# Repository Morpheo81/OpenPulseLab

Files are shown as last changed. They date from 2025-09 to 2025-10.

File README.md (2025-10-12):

# OpenPulseLab
A Low-Cost, Open-Source ECG Monitor for educational and research uses

> [!NOTE]
> This project is currently under active development and is a work in progress (WIP).

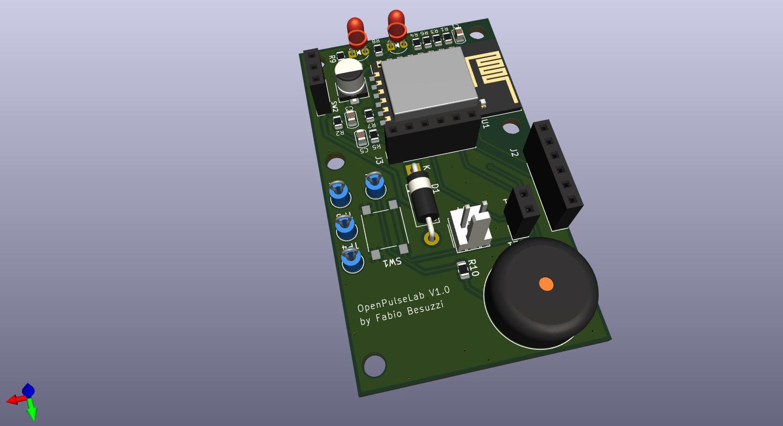
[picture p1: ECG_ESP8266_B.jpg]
ECG ESP8266

---

### A Note on Project Purpose and Responsibility

**This device is an educational and research prototype. It is NOT a certified medical device and should NEVER be used for diagnostic purposes.**

The primary goal of this project is to create an accessible, affordable, and open-source platform for learning about biometrics, signal processing, and IoT. Its simplicity is a feature, designed to lower the barrier to entry for students, hobbyists, and developers in emerging economies. The data quality is intentionally limited in this version, but can be improved with advanced software. By using this project, you acknowledge and agree to the full disclaimer below.

---

## ⚠️ Legal Disclaimer ⚠️

This project is provided "as is," without any warranty of any kind, either express or implied, including, but not limited to, the implied warranties of merchantability, fitness for a particular purpose, or non-infringement. In no event shall the authors or copyright holders be liable for any claim, damages, or other liability, whether in an action of contract, tort, or otherwise, arising from, out of, or in connection with the software, hardware, or the use or other dealings in the project.

**Do not use this device for medical diagnosis, treatment, or any clinical application. Consult a certified medical professional for any health-related concerns.**

---

### About the Project

This project leverages an **ESP8266 microcontroller** to create a simple, Wi-Fi enabled ECG monitor. It processes the analog signals from an **AD8232 ECG sensor module** and serves a web page via an on-board web server. Users can access this page from any web browser to view real-time heart data and save it. The device also includes hardware for **lead-off detection** and a **buzzer/LED** for error signaling.

* **Open and Accessible:** All hardware schematics, firmware, and documentation are provided.
* **Low-Cost:** Built with readily available and inexpensive components.
* **Self-Contained:** Designed to run on a battery, ensuring full electrical isolation and safety from the mains power supply.

### How It Works

1.  **Signal Acquisition:** The AD8232 sensor module captures the electrical signals of the heart.
2.  **Signal Conversion:** The ESP8266's analog-to-digital converter (ADC) reads the output from the AD8232.
3.  **Data Transmission:** The ESP8266 acts as a web server, broadcasting the raw data via Wi-Fi and using **WebSockets** for real-time streaming.
4.  **Data Visualization:** A simple HTML/JavaScript front-end displays the data on a graph in a web browser. A software filter (median on X, moving average on Y) is applied to smooth the raw data.

**Here an example of the Web Server running on ESP8266**
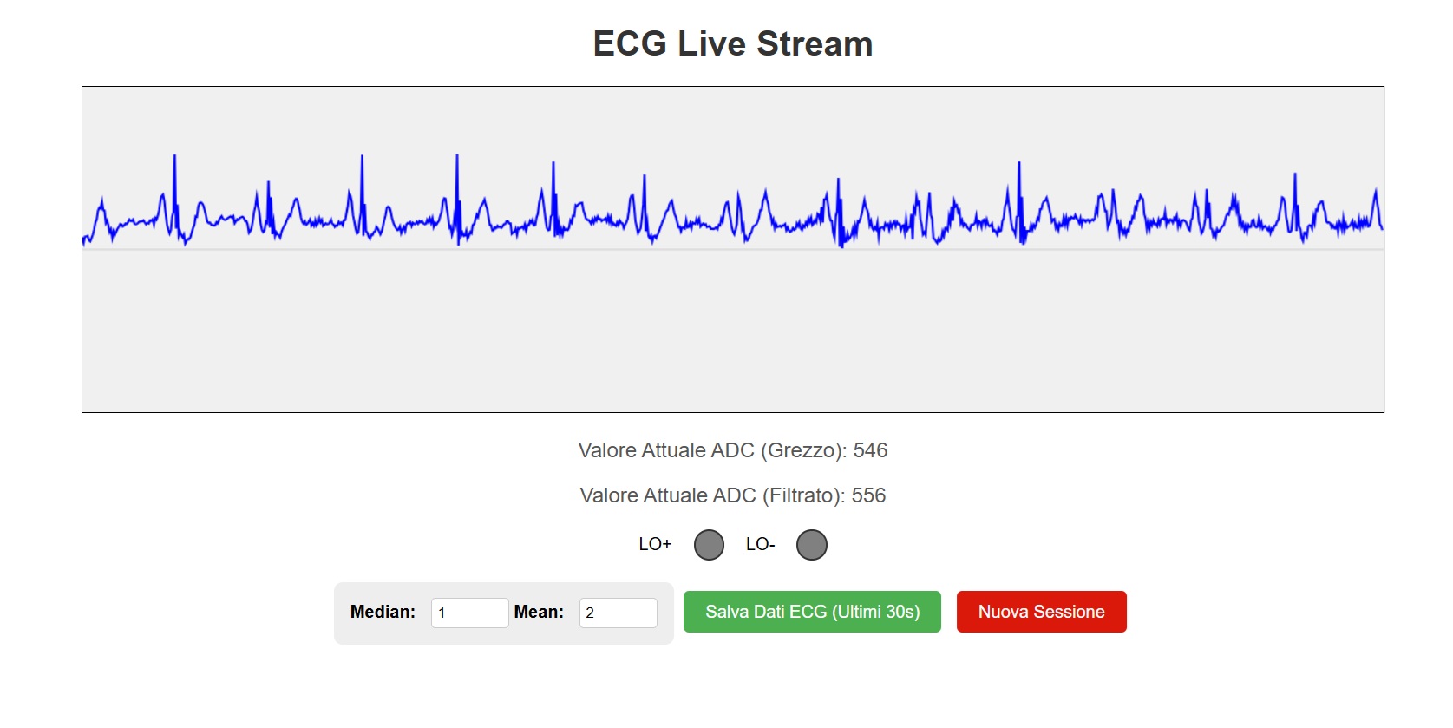
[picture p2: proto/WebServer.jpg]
WebServer


### Potential Applications

While not a medical tool, this project has several fascinating applications:

* **Educational:** A practical, hands-on tool for teaching electronics, programming, and biometrics.
* **Research:** A base platform for research into advanced signal processing algorithms (e.g., using AI to identify patterns in nerve impulses).
* **Human-Computer Interface (HCI):** The same principles can be used to detect neuromuscular signals, allowing the device to act as a controller for a PC or other machines.

### Getting Started

To build your prototipe device, you will need:

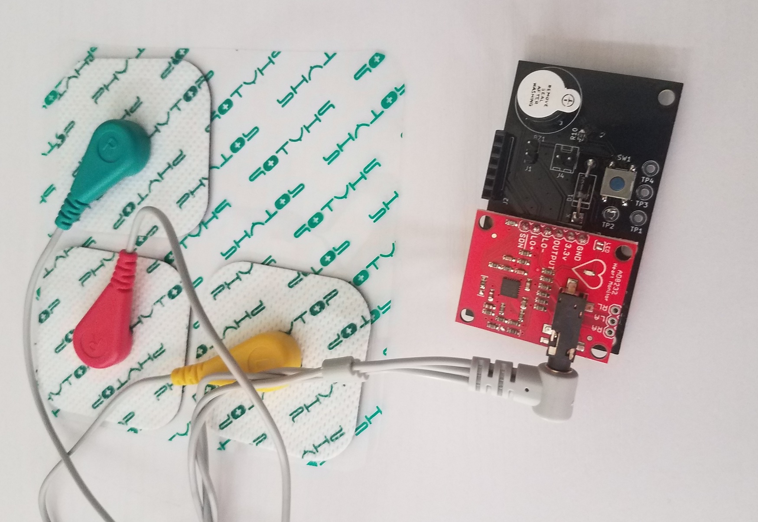
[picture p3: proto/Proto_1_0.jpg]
Board


* **Components: for Rev 1.0**
    * Buzzer (BZ1) - not mandatory
    * 0.1uF capacitors (C1, C3)
    * 100uF capacitor (C2)
    * capacitor (C5)
    * diodes (D1, D2)
    * PinSocket 1x06 (J2, J3) and 1x02 (J1) connectors
    * Molex 1x02 connector (J4)
    * LED for error (LED1)
    * LED for power (LED2)
    * 10K resistors (R1, R6)
    * 1K resistor (R2)
    * 22K resistors (R3, R4, R5)
    * 100 resistors (R8, R9, R10)
    * SW_Push button (SW1)
    * SW_DIP_x01 switch (SW2)
    * test points (TP1, TP2, TP3, TP4)
    * ESP-12F WiFi module (U1)
 NOTE: SMD resistor and ceramic capacitor are 0805
* **Tools:**
    * Soldering iron and soldering materials.
    * **AD8232 module with electrode.**
    * Serial programmer.
 
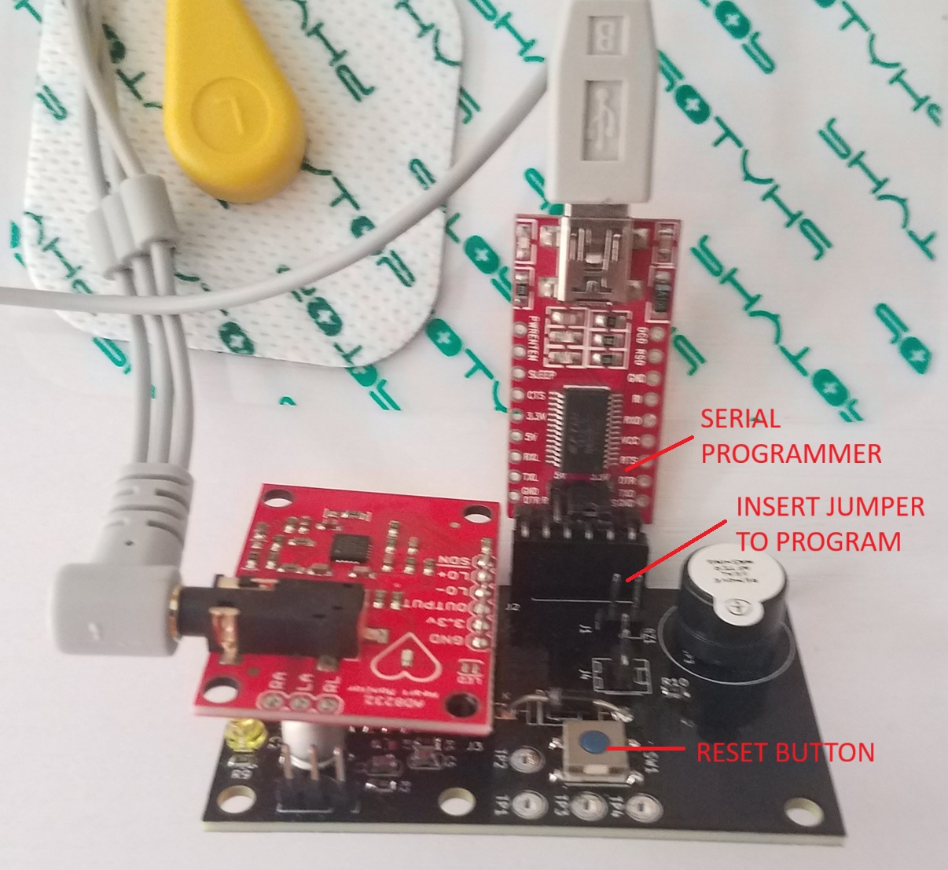
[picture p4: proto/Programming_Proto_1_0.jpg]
Programming


* **Firmware & Libraries:**
    * `ECG_ESP8266.ino` firmware file example for the ECG - main topic
    * `ECG_muscle_ESP8266.ino` firmware file example for use this platform to detect the activation of muscles
    * Arduino Libraries: `ESP8266WiFi`, `ESP8266WebServer`, `WebSocketsServer` by Markus Sattler, `ArduinoJson`
* **Files:**
    * The hardware files are in the `KiCad` folder.
    * The firmware files are in the `ArduinoIDE` folder.
    * The proto of the box is in the `FreeCAD` folder.

### Example of Electrode Placement and Important Notes

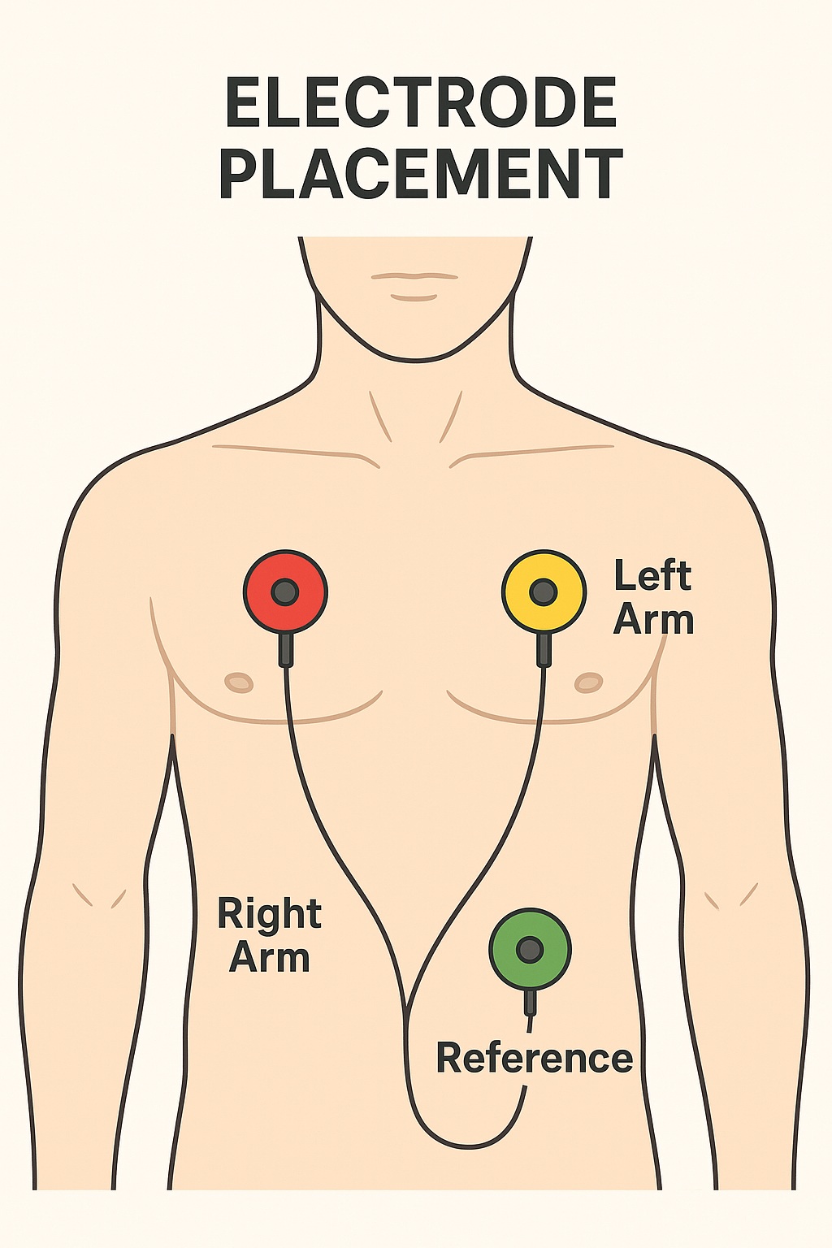
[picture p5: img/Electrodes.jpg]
descrizione


This device uses TENS/EMS (Transcutaneous Electrical Nerve Stimulation / Electrical Muscle Stimulation) electrodes instead of traditional, single-use ECG electrodes. While standard ECG electrodes are specifically designed for low impedance and optimal signal fidelity, they are often expensive and intended for single use due to their hydrogel-based adhesive.

Our choice to use TENS/EMS pads is a deliberate design decision to prioritize reusability and user convenience. These pads, commonly used for muscle stimulation, have a more durable adhesive, allowing for multiple uses before replacement. This makes the OpenPulseLab device more cost-effective and accessible, particularly for educational and hobbyist purposes.

It's important to note the technical trade-off involved. The impedance of TENS/EMS pads is typically higher than that of medical-grade ECG electrodes. This can result in a weaker signal from the AD8232 sensor. If you choose to use different types of electrodes, such as standard ECG electrodes, you may need to re-evaluate and adjust the amplification factors and any filtering thresholds within the firmware to achieve the best possible signal quality.

### Licensing

This project is released under the **Creative Commons Attribution-ShareAlike 4.0 International (CC BY-SA 4.0)** license. This means you are free to share and adapt the material for any purpose, even commercially, as long as you provide appropriate attribution and distribute your contributions under the same license.

**Copyright (c) 2025 Fabio Besuzzi**

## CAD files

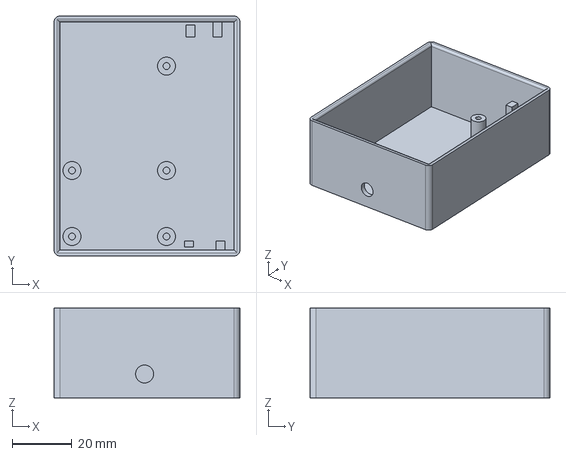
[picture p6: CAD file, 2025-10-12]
FreeCAD/Scatola_ECG.FCStd
62.0 x 80.0 x 30.0 mm

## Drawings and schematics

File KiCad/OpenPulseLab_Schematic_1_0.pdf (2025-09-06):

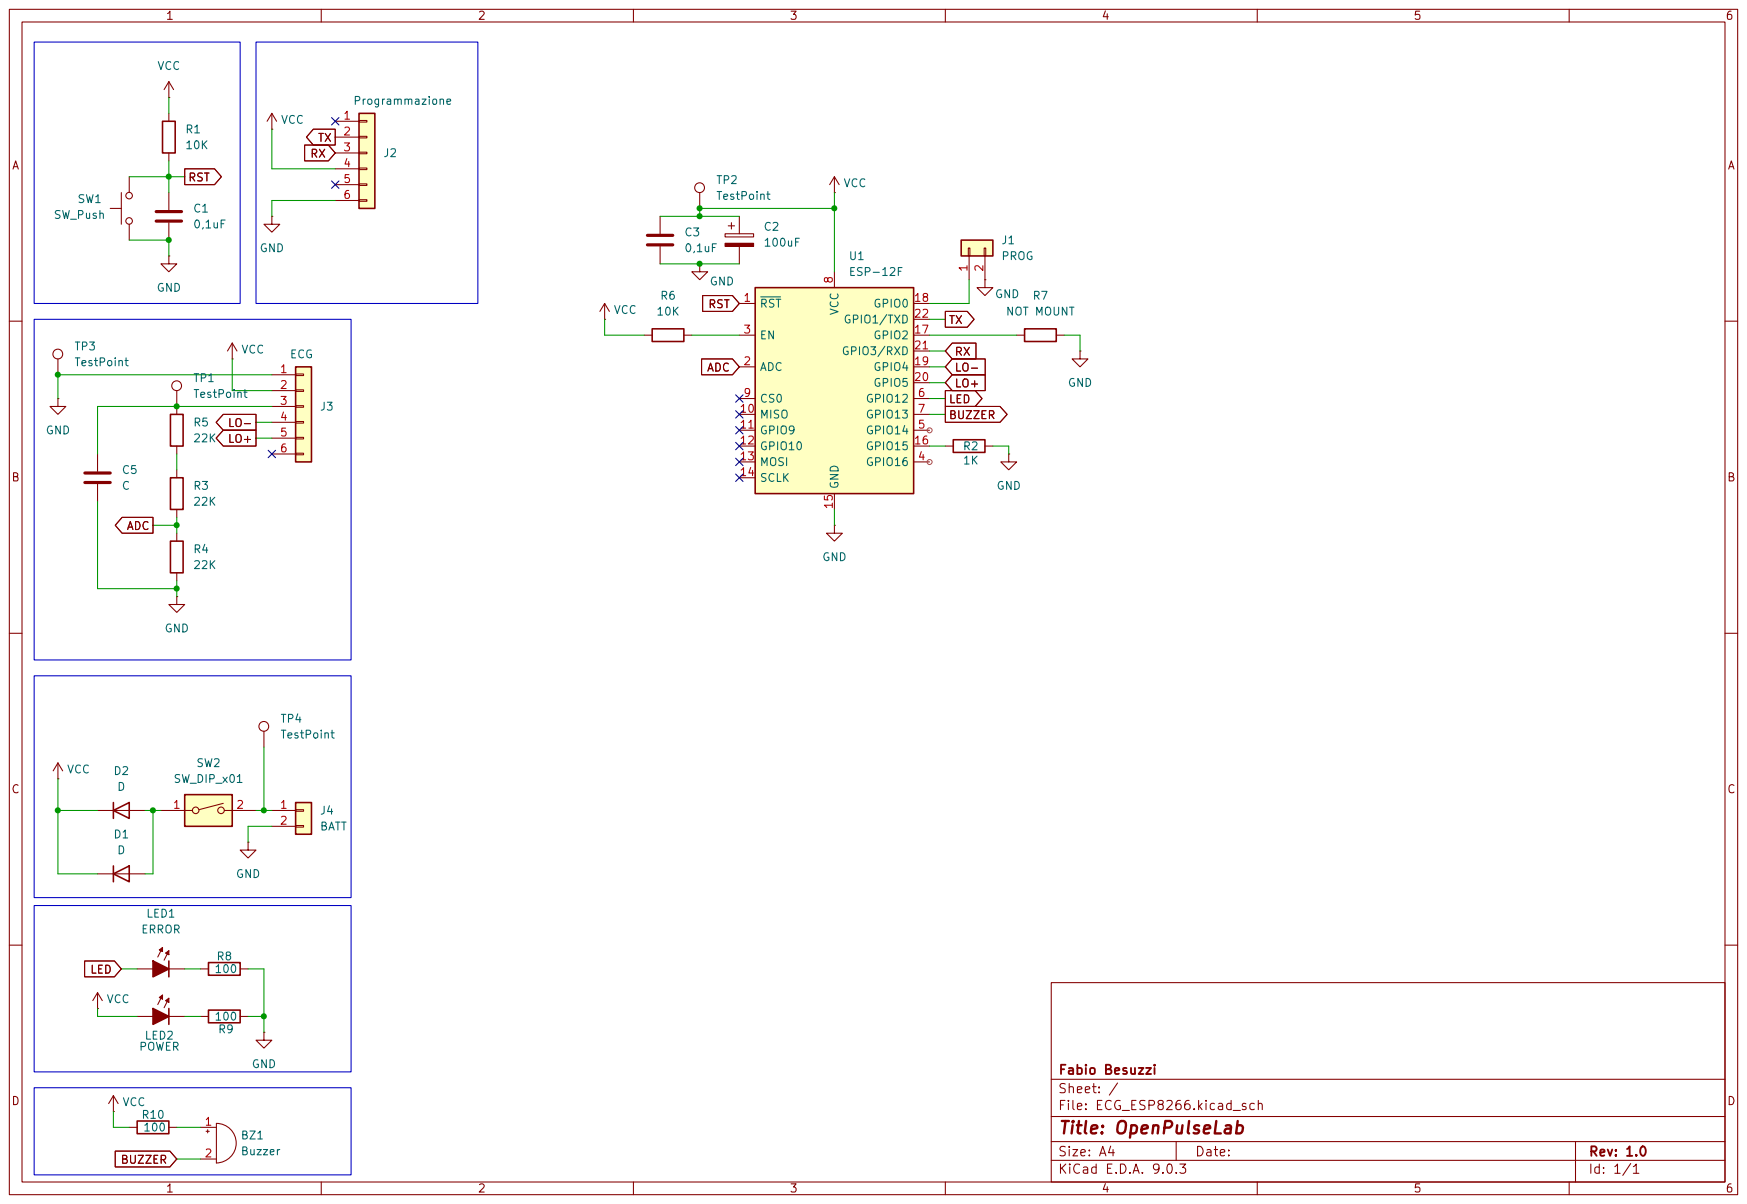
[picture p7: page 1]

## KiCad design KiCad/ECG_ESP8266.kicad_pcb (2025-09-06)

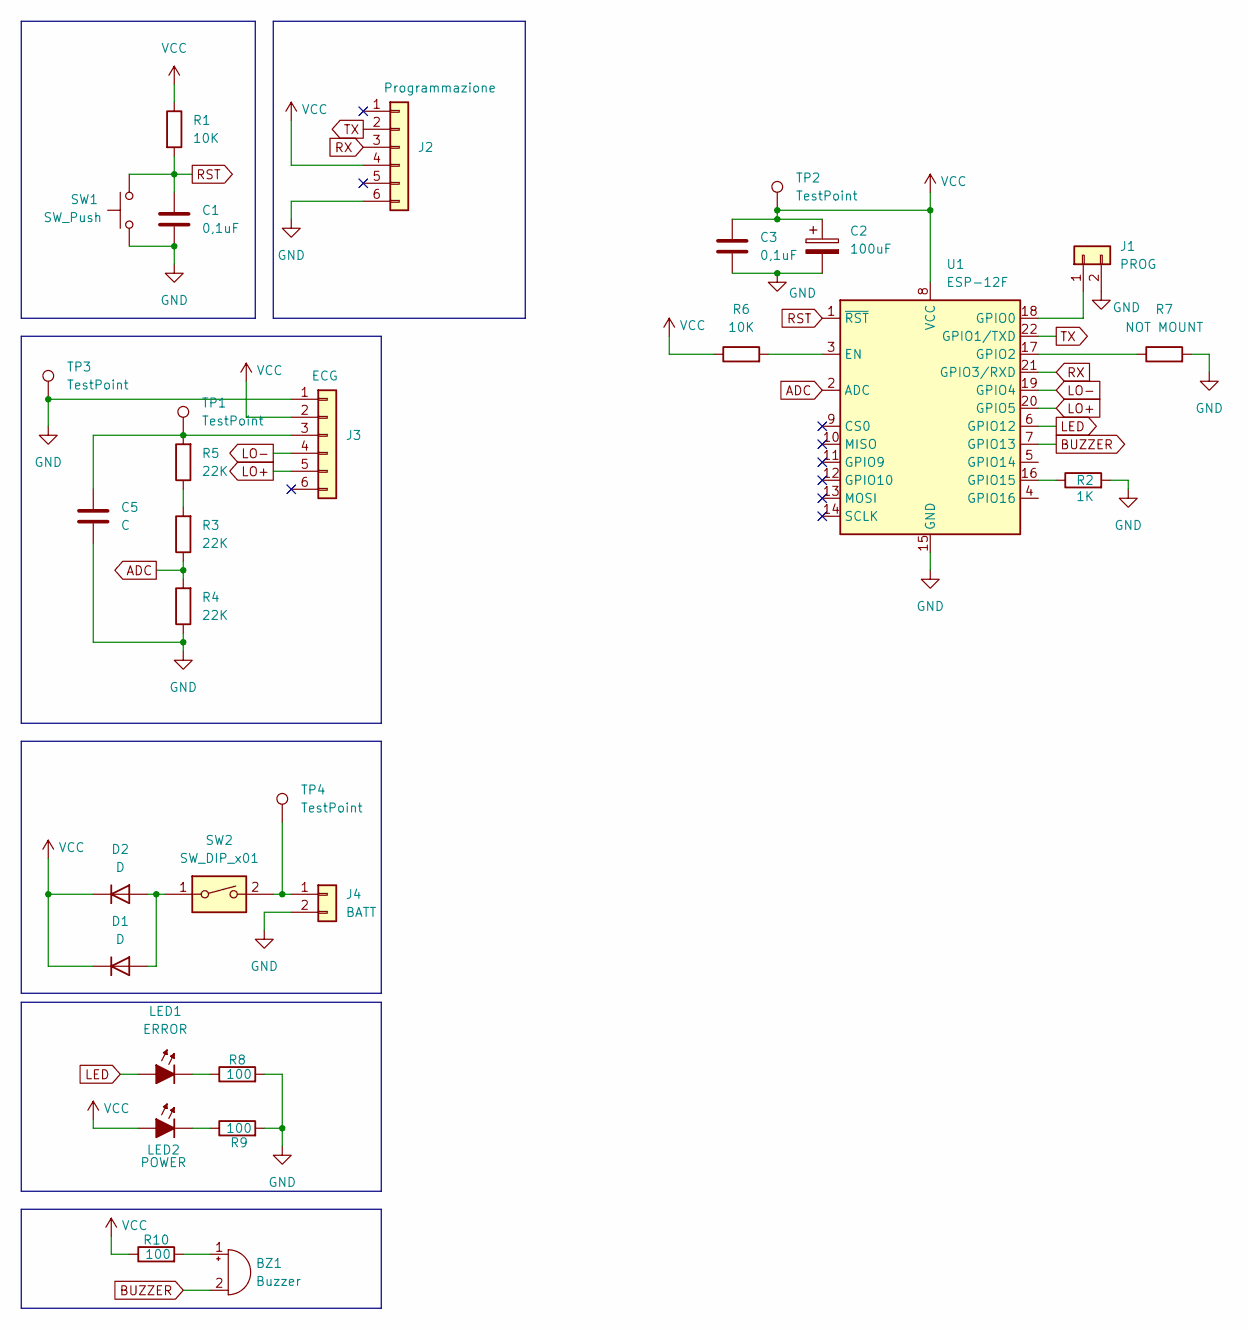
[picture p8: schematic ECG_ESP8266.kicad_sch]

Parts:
BZ1: Buzzer; Buzzer_15x7.5RM7.6
C1, C3: 0,1uF; C_0805_2012Metric
C2: 100uF; CP_Elec_5x5.3
C5: C; C_0805_2012Metric
D1: D; D_DO-15_P12.70mm_Horizontal
D2: D; D_0805_2012Metric
J1: PROG; PinSocket_1x02_P2.54mm_Vertical
J2: Programmazione; PinSocket_1x06_P2.54mm_Vertical
J3: ECG; PinSocket_1x06_P2.54mm_Vertical
J4: BATT; Molex_KK-254_AE-6410-02A_1x02_P2.54mm_Vertical
LED1: ERROR; LED_D3.0mm
LED2: POWER; LED_D3.0mm
R1, R6: 10K; R_0805_2012Metric
R2: 1K; R_0805_2012Metric
R3, R4, R5: 22K; R_0805_2012Metric
R7: NOT MOUNT; R_0805_2012Metric
R8, R9, R10: 100; R_0805_2012Metric
SW1: SW_Push; SW_Push_1P1T_NO_6x6mm_H9.5mm
SW2: SW_DIP_x01; PinSocket_1x03_P2.54mm_Vertical
TP1, TP2, TP3, TP4: TestPoint; TestPoint_Loop_D2.54mm_Drill1.5mm_Beaded
U1: ESP-12F; ESP-12E

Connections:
ADC: R3.1, R4.2, U1.2 (ADC)
BUZZER: BZ1.2 (-), U1.7 (GPIO13)
GND: C1.2, C2.2, C3.2, C5.2, J1.2, J2.6, J3.1, J4.2, R2.2, R4.1, R7.2, R8.2, R9.2, SW1.1, TP3.1, U1.15 (GND)
LED: LED1.2 (A), U1.6 (GPIO12)
LO+: J3.5, U1.20 (GPIO5)
LO-: J3.4, U1.19 (GPIO4)
unnamed: BZ1.1 (+), R10.2
unnamed: D1.2 (A), D2.2 (A), SW2.1
unnamed: J1.1, U1.18 (GPIO0)
unnamed: C5.1, J3.3, R5.2, TP1.1
unnamed: J4.1, SW2.2, TP4.1
unnamed: LED1.1 (K), R8.1
unnamed: LED2.1 (K), R9.1
unnamed: R3.2, R5.1
unnamed: R6.2, U1.3 (EN)
unnamed: R7.1, U1.17 (GPIO2)
unnamed: R2.1, U1.16 (GPIO15)
RST: C1.1, R1.2, SW1.2, U1.1 (~RST)
RX: J2.3, U1.21 (GPIO3/RXD)
TX: J2.2, U1.22 (GPIO1/TXD)
VCC: C2.1, C3.1, D1.1 (K), D2.1 (K), J2.4, J3.2, LED2.2 (A), R1.1, R6.1, R10.1, TP2.1, U1.8 (VCC)

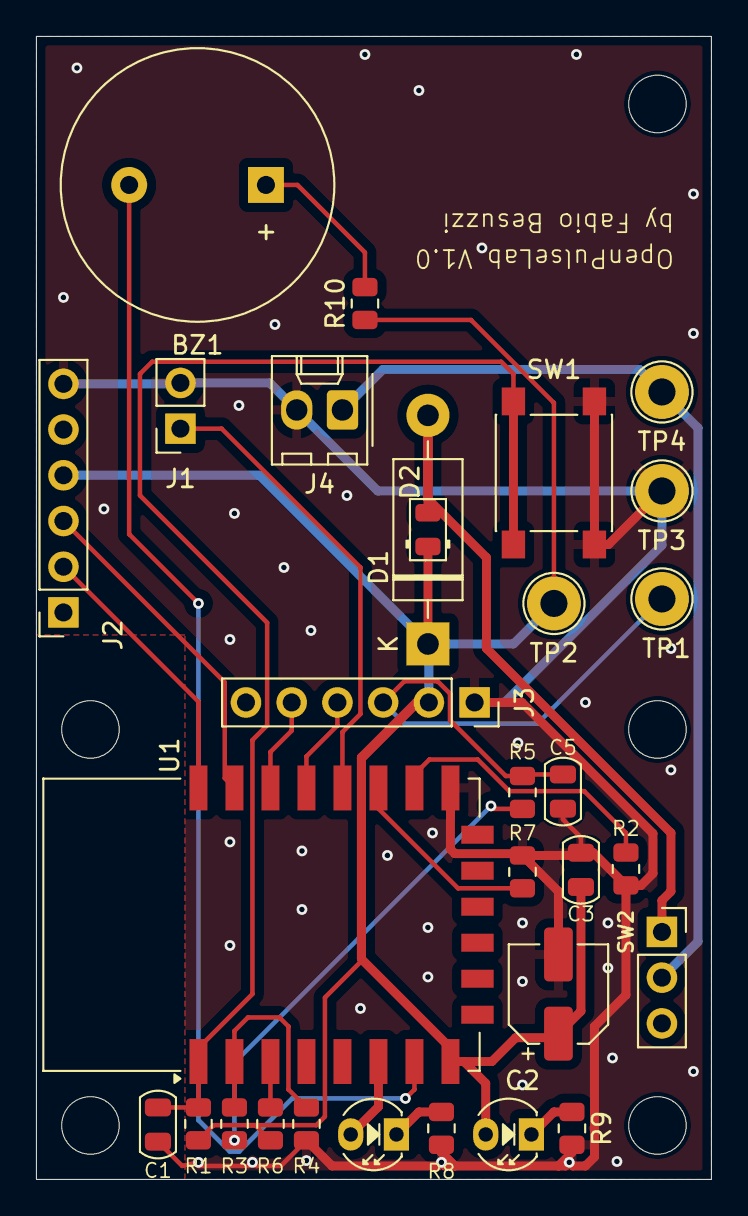
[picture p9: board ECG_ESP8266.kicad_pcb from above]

Board: 2 copper layers, 37.5 x 63.5 mm, 30 parts (0 on the bottom side), 21 nets.

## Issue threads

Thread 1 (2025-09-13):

Box for the device

Morpheo81, 2025-09-13:
Design of a case for the device with STL files printable via 3D printing. The case should be reasonably ergonomic and compact, and it must contain an 18650 battery to power the device.

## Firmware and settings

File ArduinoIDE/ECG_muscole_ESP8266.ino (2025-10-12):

#include <ESP8266WiFi.h>
#include <ESP8266WebServer.h>
#include <WebSocketsServer.h> // Libreria WebSockets di Markus Sattler
#include <ArduinoJson.h>      // Libreria per la gestione di JSON (installala!)

// --- Configurazione Wi-Fi Access Point ---
const char *ssid = "ECG_Monitor";     // Nome della rete Wi-Fi che l'ESP creerà
const char *password = "password123"; // Password della rete (puoi lasciarla vuota: const char *password = ""; per nessuna password)

// --- Inizializzazione dei Server ---
ESP8266WebServer server(80);         // Server HTTP sulla porta 80
WebSocketsServer webSocket = WebSocketsServer(81); // Server WebSockets sulla porta 81

// --- Configurazione Pin Lead-Off Detection (AD8232) ---
// Collega LO+ del AD8232 a D2 (GPIO4) e LO- a D1 (GPIO5) sul tuo NodeMCU/Wemos.
// Verifica la tua board per i pin GPIO effettivi associati a D1, D2, ecc.
// L'AD8232 invia HIGH quando il lead è scollegato, LOW quando è connesso.
// Se il tuo modulo ha logica invertita, potresti dover invertire i 0/1 nel JS.
const int LO_PLUS_PIN = 4;  // Esempio: pin D2 (GPIO4) collegato a LO+ del AD8232
const int LO_MINUS_PIN = 5; // Esempio: pin D1 (GPIO5) collegato a LO- del AD8232

// Pin del LED aggiuntivo da utilizzare per segnalazioni di errori o stato di funzionamento (GPIO12)
const int LED_PIN = 12;

// Pin del BUZZER da utilizzare per allarmi (GPIO13)
const int BUZZER_PIN = 13;


// --- Pagina HTML da servire al Browser ---
// Contiene HTML, CSS e JavaScript per la visualizzazione e le funzionalità
const char* htmlPage = R"rawliteral(

<!DOCTYPE html>
<html>
<head>
    <title>EMG Muscolare Differenziale</title>
    <meta name="viewport" content="width=device-width, initial-scale=1">
    <style>
        body { font-family: Arial, sans-serif; text-align: center; margin-top: 50px; }
        /* Il canvas non è più necessario ma manteniamo lo stile per consistenza, nascondendolo o rimuovendolo */
        canvas { display: none; } 
        h1 { color: #333; }
        p { font-size: 1.2em; color: #555; }
        /* Stile per i parametri di controllo */
        .control-params {
            margin-top: 20px;
            background-color: #eee;
            padding: 15px;
            border-radius: 8px;
            display: inline-block;
            text-align: left;
        }
        .control-params label {
            display: block;
            margin-top: 10px;
            font-weight: bold;
        }
        .control-params input[type="number"] {
            width: 80px;
            padding: 5px;
            border-radius: 4px;
            border: 1px solid #ccc;
        }
        /* Stile per gli indicatori */
        .indicator-container {
            margin-top: 30px;
            margin-bottom: 30px;
            display: flex;
            justify-content: center;
            gap: 40px;
            align-items: center;
        }
        .indicator-group {
            text-align: center;
        }
        .indicator-label {
            font-size: 1.5em;
            font-weight: bold;
            color: #333;
            margin-bottom: 10px;
        }
        .indicator {
            width: 40px;
            height: 40px;
            border-radius: 50%;
            background-color: gray; /* Spento */
            border: 3px solid #333;
            box-shadow: 0 0 10px rgba(0, 0, 0, 0.2);
            transition: background-color 0.1s;
        }
        .indicator.active-muscle-1 {
            background-color: #2196F3; /* Blu per Muscolo 1 */
            box-shadow: 0 0 20px #2196F3, 0 0 30px #2196F3;
        }
        .indicator.active-muscle-2 {
            background-color: #FFC107; /* Giallo/Arancio per Muscolo 2 */
            box-shadow: 0 0 20px #FFC107, 0 0 30px #FFC107;
        }
    </style>
</head>
<body>
    <h1>Muscle Activations</h1>

    <div class="indicator-container">
        <div class="indicator-group">
            <div class="indicator-label">MUSCLE 1</div>
            <div id="muscle1Indicator" class="indicator"></div>
        </div>
        <div class="indicator-group">
            <div class="indicator-label">MUSCLE 2</div>
            <div id="muscle2Indicator" class="indicator"></div>
        </div>
    </div>
    
    <p>DATA: ROW: <span id="currentActivityValue">--</span></p>
    <p>DATA: Filtered: <span id="currentNormalizedValue">--</span></p>

    <div class="control-params">
        <h3>Sensibility</h3>
        
        <label for="activationThreshold">Treshold (0-512):</label>
        <input type="number" id="activationThreshold" value="50" min="1" max="512">
        
        <label for="sensitivityFactor">Amplification:</label>
        <input type="number" id="sensitivityFactor" value="1.0" min="0.1" step="0.1">
    </div>

    <canvas id="ecgCanvas" width="1" height="1"></canvas> 
    
    <script>
        var ws;
        var adcMidPoint = 512; // Punto medio per un ADC a 10 bit (0-1023)
        
        // --- Elementi UI ---
        var muscle1Indicator = document.getElementById('muscle1Indicator');
        var muscle2Indicator = document.getElementById('muscle2Indicator');
        var thresholdInput = document.getElementById('activationThreshold');
        var sensitivityInput = document.getElementById('sensitivityFactor');
        
        // --- Parametri di Controllo ---
        var threshold = parseFloat(thresholdInput.value);
        var sensitivity = parseFloat(sensitivityInput.value);

        // Event Listeners per i cambiamenti dei valori
        thresholdInput.addEventListener('change', function() {
            threshold = parseFloat(this.value);
            console.log('Soglia aggiornata:', threshold);
        });
        sensitivityInput.addEventListener('change', function() {
            sensitivity = parseFloat(this.value);
            console.log('Sensibilità aggiornata:', sensitivity);
        });

        // --- Funzione Principale di Attivazione Muscolare ---
        function checkMuscleActivation(rawValue) {
            // 1. Calcola lo scostamento dal punto medio (segnala quale muscolo è attivo)
            // Se rawValue > 512, lo scostamento è positivo (Muscolo 1, es. Flessore)
            // Se rawValue < 512, lo scostamento è negativo (Muscolo 2, es. Estensore)
            var deviation = rawValue - adcMidPoint;

            // 2. Calcola l'intensità (attività) in valore assoluto
            var absoluteActivity = Math.abs(deviation);
            
            // 3. Applica il fattore di sensibilità (amplificazione)
            var normalizedActivity = absoluteActivity * sensitivity;

            // 4. Aggiorna i valori visualizzati
            document.getElementById('currentActivityValue').innerText = deviation.toFixed(0);
            document.getElementById('currentNormalizedValue').innerText = normalizedActivity.toFixed(0);

            // 5. Logica di Attivazione
            if (normalizedActivity > threshold) {
                // L'attività è abbastanza forte
                if (deviation > 0) {
                    // Muscolo 1 è dominante (scostamento positivo)
                    muscle1Indicator.classList.add('active-muscle-1');
                    muscle2Indicator.classList.remove('active-muscle-2');
                    console.log("Muscolo 1 ATTIVO (Flessione)");
                } else {
                    // Muscolo 2 è dominante (scostamento negativo)
                    muscle2Indicator.classList.add('active-muscle-2');
                    muscle1Indicator.classList.remove('active-muscle-1');
                    console.log("Muscolo 2 ATTIVO (Estensione)");
                }
            } else {
                // Nessuna attività sufficiente
                muscle1Indicator.classList.remove('active-muscle-1');
                muscle2Indicator.classList.remove('active-muscle-2');
            }
        }

        // --- Funzione per Connettersi al WebSocket ---
        function connectWebSocket() {
            ws = new WebSocket('ws://' + location.hostname + ':81/');

            ws.onopen = function() {
                console.log('WebSocket Connesso!');
            };

            ws.onmessage = function(event) {
                // Assumiamo che l'ESP8266 invii ancora un JSON con il valore ADC
                try {
                    var dataPacket = JSON.parse(event.data);
                    var rawValue = dataPacket.ecg; // Riusiamo la chiave 'ecg' ma ora rappresenta l'EMG
                    
                    if (!isNaN(rawValue)) {
                        checkMuscleActivation(rawValue);
                    }
                } catch (e) {
                    console.error("Errore nel parsing JSON o dati non validi:", e, event.data);
                }
            };

            ws.onclose = function() {
                console.log('WebSocket Disconnesso, tento di riconnettermi...');
                // Spegne le spie in caso di disconnessione
                muscle1Indicator.classList.remove('active-muscle-1');
                muscle2Indicator.classList.remove('active-muscle-2');
                setTimeout(connectWebSocket, 3000); // Tenta di riconnettersi dopo 3 secondi
            };

            ws.onerror = function(error) {
                console.error('Errore WebSocket:', error);
            };
        }

        // --- Inizializzazione all'apertura della Pagina ---
        window.onload = function() {
            connectWebSocket(); // Avvia la connessione WebSocket
        };
    </script>
</body>
</html>

)rawliteral";

// --- Gestore Eventi WebSockets ---
void webSocketEvent(uint8_t num, WStype_t type, uint8_t * payload, size_t length) {
  switch(type) {
    case WStype_DISCONNECTED:
      Serial.printf("[%u] Client Disconnesso!\n", num);
      break;
    case WStype_CONNECTED: {
      IPAddress ip = webSocket.remoteIP(num);
      Serial.printf("[%u] Client Connesso da %d.%d.%d.%d URL: %s\n", num, ip[0], ip[1], ip[2], ip[3], payload);
      webSocket.sendTXT(num, "Benvenuto al monitor ECG!"); // Invia un messaggio di benvenuto al nuovo client
    }
    break;
    case WStype_TEXT:
      Serial.printf("[%u] Ricevuto testo: %s\n", num, payload);
      // Puoi aggiungere logica qui se il browser invia comandi all'ESP
      break;
    case WStype_BIN:
    case WStype_PING:
    case WStype_PONG:
    case WStype_ERROR:
      // Ignora questi tipi di messaggi per questo progetto
      break;
  }
}

// --- Funzione di Setup (Eseguita una sola volta all'avvio dell'ESP) ---
void setup() {
  Serial.begin(115200); // Inizializza la comunicazione seriale per il debug
  Serial.println("\n");
  Serial.println("Avvio ECG Monitor...");

  // Configura i pin per la Lead-Off Detection come input
  // L'AD8232 tipicamente ha uscite Lead-Off che sono HIGH (pull-up interno)
  // quando l'elettrodo è scollegato, e LOW quando è collegato.
  // Quindi, INPUT sarà sufficiente. Se hai problemi, prova INPUT_PULLUP.
  pinMode(LO_PLUS_PIN, INPUT);
  pinMode(LO_MINUS_PIN, INPUT);

  //Configurazione dei pin del LED e del BUZZER 
  pinMode(LED_PIN, OUTPUT);
  pinMode(BUZZER_PIN, OUTPUT);
  //Impostazione del valore di default: il LED è attivo alto mentre il BUZZER è attivo basso
  digitalWrite(LED_PIN, LOW);
  digitalWrite(BUZZER_PIN, HIGH);


  // Configura l'ESP come Access Point Wi-Fi
  WiFi.softAP(ssid, password);
  Serial.print("Access Point \"");
  Serial.print(ssid);
  Serial.println("\" creato.");
  Serial.print("Indirizzo IP per la connessione: ");
  Serial.println(WiFi.softAPIP()); // Stampa l'IP dell'ESP (solitamente 192.168.4.1)

  // Configura il server HTTP per servire la pagina web
  server.on("/", HTTP_GET, []() {
    server.send(200, "text/html", htmlPage); // Invia la pagina HTML al browser
  });
  server.begin();
  Serial.println("Server HTTP avviato sulla porta 80.");

  // Avvia il server WebSockets e registra la funzione di callback per gli eventi
  webSocket.begin();
  webSocket.onEvent(webSocketEvent);
  Serial.println("Server WebSockets avviato sulla porta 81.");

  // Inizializza il pin analogico A0
  // La risoluzione ADC è nativamente a 10 bit sull'ESP8266, quindi analogRead() fornirà valori 0-1023.
  Serial.println("ADC configurato nativamente a 10 bit.");
  Serial.println("Pronto per lo streaming ECG.");
}

int ecgValue;

// --- Funzione Loop (Eseguita continuamente dopo il setup) ---
void loop() {
  // Gestisce le richieste del server HTTP (per servire la pagina web)
  server.handleClient();
  // Gestisce gli eventi del server WebSockets (nuove connessioni, messaggi, ecc.)
  webSocket.loop();


  // Legge lo stato dei pin di Lead-Off Detection
  // L'AD8232 tipicamente invia HIGH (1) quando il lead è scollegato (problema),
  // e LOW (0) quando è collegato (OK).
  int loPlusStatus = digitalRead(LO_PLUS_PIN);
  int loMinusStatus = digitalRead(LO_MINUS_PIN);
int temp_ECG[9];
digitalWrite(LED_PIN, LOW);
  int c1;
  int c2;
  int c3;
  for(c1=0;c1<5;c1++) temp_ECG[c1] = 0;
  for(c1=0;c1<5;c1++)
  {
    ecgValue = analogRead(A0);
    digitalWrite(BUZZER_PIN, HIGH);
    if(ecgValue>760){
      digitalWrite(BUZZER_PIN, LOW);
      digitalWrite(LED_PIN, HIGH);
    }
    for(c2=0;c2<5-1;c2++)
    {    
      if(ecgValue>temp_ECG[c2])
      {
        for(c3=c2;c3<5-1;c3++)
        {
          temp_ECG[c3+1]=temp_ECG[c3];
        }
        temp_ECG[c2] = ecgValue;
        c2=1000;
      }
    }
  }
  ecgValue = temp_ECG[3];

delay(8);

  // Prepara un oggetto JSON con i dati ECG e gli stati di Lead-Off
  StaticJsonDocument<64> doc; // Dimensione adatta per un piccolo JSON (64 byte sono abbondanti)
  doc["ecg"] = (ecgValue-512)*2;
  doc["lo_plus"] = loPlusStatus;
  doc["lo_minus"] = loMinusStatus;

  // Serializza l'oggetto JSON in una stringa
  String jsonString;
  serializeJson(doc, jsonString);

  // Invia la stringa JSON a tutti i client WebSockets connessi
  webSocket.broadcastTXT(jsonString.c_str());


  // Legge il valore analogico dal pin A0 (uscita dell'AD8232)
  //int ecgValue = (analogRead(A0) + analogRead(A0))/2;
  /*int temp_ECG[9];
  
  
  digitalWrite(LED_PIN, LOW);
  int c1;
  int c2;
  int c3;
  for(c1=0;c1<9;c1++) temp_ECG[c1] = 0;
  for(c1=0;c1<9;c1++)
  {
    ecgValue = analogRead(A0);
    digitalWrite(BUZZER_PIN, HIGH);
    delay(1);
    if(ecgValue>760){
      digitalWrite(BUZZER_PIN, LOW);
      digitalWrite(LED_PIN, HIGH);
    }
    for(c2=0;c2<9-1;c2++)
    {    
      if(ecgValue>temp_ECG[c2])
      {
        for(c3=c2;c3<9-1;c3++)
        {
          temp_ECG[c3+1]=temp_ECG[c3];
        }
        temp_ECG[c2] = ecgValue;
        c2=1000;
      }
    }
  }
  ecgValue = temp_ECG[5];
 */



 //Serial.println(ecgValue);
 delay(1);
}

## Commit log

2025-09-06 Update LICENSE
    Aggiornamento licenza secondo suggerimenti di Gemini
2025-09-06 KiCad project for the ESP8266 board
2025-09-06 Example of ESP8266 Web Server for Arduino IDE
2025-09-06 Create KiCad
2025-09-06 KiCad Project
2025-09-06 KiCad schematic
    [ECG_ESP8266.kicad_sch]
2025-09-06 KiCad Board
    [ECG_ESP8266.kicad_pcb]
2025-09-06 Proto Board 1.0
2025-09-13 Electrodes position
2025-09-13 Update README.md
    Electrodes position example
2025-09-13 New FW with Buzzer and LED
    [ECG_ESP8266.ino]
2025-09-14 Update README.md
    Note on TENS/EMS electrode
2025-10-12 FreeCAD prototype project
    [Scatola_ECG.FCStd]
2025-10-12 Update README.md
    Some changes after adding FreeCAD files and an example on how to use this devices to control muscles activations.
